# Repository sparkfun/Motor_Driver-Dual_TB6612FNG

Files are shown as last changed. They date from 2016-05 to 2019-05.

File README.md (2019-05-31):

SparkFun Motor Driver - Dual TB6612FNG (1A)
========================================

<table class="table table-hover table-striped table-bordered">
  <tr align="center">
   <td><a href="https://cdn.sparkfun.com/assets/parts/1/2/4/8/4/14451-01.jpg">SparkFun Motor Driver - Dual TB6612FNG (1A)</a></td>
   <td><a href="https://cdn.sparkfun.com/assets/parts/1/2/4/8/2/14450a-01.jpg">SPARKFUN MOTOR DRIVER - DUAL TB6612FNG (1A) with Headers</a></td>
  </tr>
  <tr align="center">
    <td>SparkFun Motor Driver - Dual TB6612FNG (1A) w/out Headers [<a href="https://www.sparkfun.com/products/14451">ROB-14451</a>]</td>
    <td>SparkFun Motor Driver - Dual TB6612FNG with Headers [<a href="https://www.sparkfun.com/products/14450">ROB-14450</a>]</td>
  </tr>
</table>

The TB6612FNG motor driver can control up to two DC motors at a constant current of 1.2A (3.2A peak). Two input signals (IN1 and IN2) can be used to control the motor in one of four function modes - CW, CCW, short-brake, and stop. The two motor outputs (A and B) can be separately controlled, the speed of each motor is controlled via a PWM input signal with a frequency up to 100kHz. The STBY pin should be pulled high to take the motor out of standby mode.

Repository Contents
-------------------

* **/Hardware** - Eagle design files (.brd, .sch)

Documentation
--------------

* **[Hookup Guide](https://learn.sparkfun.com/tutorials/tb6612fng-hookup-guide)** - Basic hookup guide for the TB6612FNG dual motor driver.
* **[SparkFun Fritzing repo](https://github.com/sparkfun/Fritzing_Parts)** - Fritzing diagrams for SparkFun products.
* **[SparkFun 3D Model repo](https://github.com/sparkfun/3D_Models)** - 3D models of SparkFun products. 

Product Versions
----------------
* [ROB-14450](https://www.sparkfun.com/products/14450)- V11 With Headers
* [ROB-14451](https://www.sparkfun.com/products/14451)- V11 Without headers
* *[ROB-13845 (RETIRED)](https://www.sparkfun.com/products/13845)- With Headers*
* *[ROB-09457 (RETIRED)](https://www.sparkfun.com/products/retired/9457)- Without headers*

Version History
---------------
* [v11](https://github.com/sparkfun/Motor_Driver-Dual_TB6612FNG/releases/tag/V_11) - Revision with Silkscreen/Components Update, v11
* [v1.1b](https://github.com/sparkfun/Motor_Driver-Dual_TB6612FNG/releases/tag/V_1.1b) - Minor update
* [v1.1](https://github.com/sparkfun/Motor_Driver-Dual_TB6612FNG/releases/tag/V_1.1) - Initial Release 

License Information
-------------------

This product is _**open source**_! 

Please review the LICENSE.md file for license information. 

If you have any questions or concerns on licensing, please contact techsupport@sparkfun.com.

Distributed as-is; no warranty is given.

- Your friends at SparkFun.

_<COLLABORATION CREDIT>_

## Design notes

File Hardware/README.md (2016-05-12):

SparkFun <PRODUCT NAME> Design Files
=====================================

The .sch and .brd files hare are Eagle CAD schematic and PCB design files from SparkFun Electronics.
A freeware version of Eagle can be found [here](http://www.cadsoftusa.com/download-eagle/freeware/).

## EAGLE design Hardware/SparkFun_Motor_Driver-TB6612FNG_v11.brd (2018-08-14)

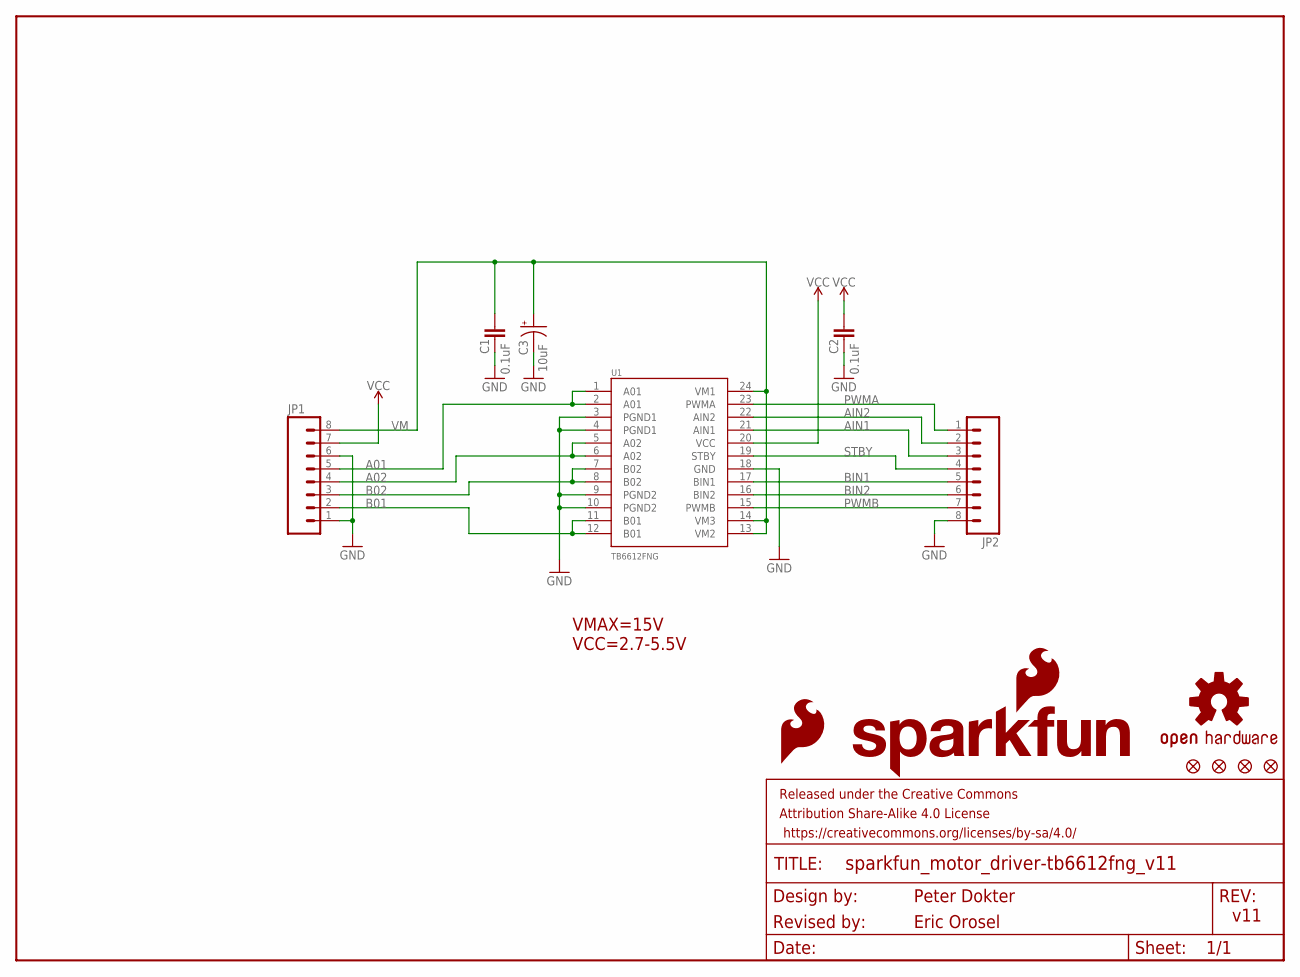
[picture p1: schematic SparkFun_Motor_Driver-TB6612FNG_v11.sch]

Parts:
C1, C2: 0.1uF; 0402
C3: 10uF; EIA3528
FD1, FD2, FD3, FD4: FIDUCIALUFIDUCIAL; FIDUCIAL-MICRO
FRAME1: FRAME-LETTER; CREATIVE_COMMONS
JP1, JP2: M0875_PERCENT_REDUCED; 1X08_OFFSET_REDUCED
LOGO1: SFE_LOGO_FLAME.1_INCH; SFE_LOGO_FLAME_.1
LOGO2: OSHW-LOGOS; OSHW-LOGO-S
LOGO4: SFE_LOGO_NAME_FLAME.1_INCH; SFE_LOGO_NAME_FLAME_.1
U1: TB6612FNG; SSOP24

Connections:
A01: JP1.5, U1.1 (A01), U1.2 (A01)
A02: JP1.4, U1.5 (A02), U1.6 (A02)
AIN1: JP2.3, U1.21 (AIN1)
AIN2: JP2.2, U1.22 (AIN2)
B01: JP1.2, U1.11 (B01), U1.12 (B01)
B02: JP1.3, U1.7 (B02), U1.8 (B02)
BIN1: JP2.5, U1.17 (BIN1)
BIN2: JP2.6, U1.16 (BIN2)
GND: C1.2, C2.2, C3.C (-), JP1.1, JP1.6, JP2.8, U1.3 (PGND1), U1.4 (PGND1), U1.9 (PGND2), U1.10 (PGND2), U1.18 (GND)
PWMA: JP2.1, U1.23 (PWMA)
PWMB: JP2.7, U1.15 (PWMB)
STBY: JP2.4, U1.19 (STBY)
VCC: C2.1, JP1.7, U1.20 (VCC)
VM: C1.1, C3.A (+), JP1.8, U1.13 (VM2), U1.14 (VM3), U1.24 (VM1)

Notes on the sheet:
v11
Peter Dokter
Revised by:
Eric Orosel
VMAX=15V VCC=2.7-5.5V

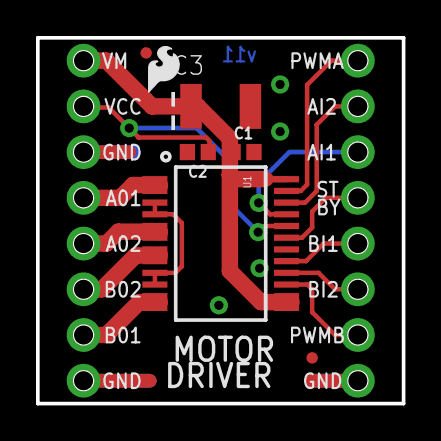
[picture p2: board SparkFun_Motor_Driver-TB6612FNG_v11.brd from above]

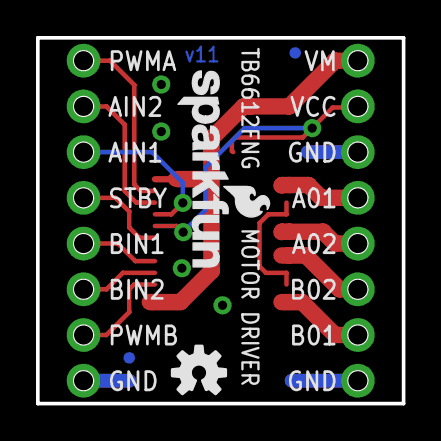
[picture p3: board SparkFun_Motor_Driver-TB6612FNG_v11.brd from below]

Board: 2 copper layers, 20.3 x 20.3 mm, 14 parts (4 on the bottom side), 14 nets.

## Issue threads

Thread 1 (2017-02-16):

Chip is mislabeled in the schematic.

Funda, 2017-02-16:
The schematic for both 09457 and 13845 label the chip incorrectly. We have the chip itself labeled "TB6621FNG" instead of "TB6612FNG".  Also, the schematic on the 13845 product page is the old v10 version.

ElhemEnohpi, 2017-09-15:
There's now an erroneous package in EasyEDA, tagged "SparkFun", which seems to be spreading this to other schematics:
https://easyeda.com/component/TB6621FNG-LmyKIGDBz
https://s3.amazonaws.com/digistump-resources/files/9adf044f_motor.pdf

ToniCorinne, 2017-09-18:
@ericorosel can you take a look at this? If we need to fix this on the updated board version, I'd like to address this.

ericorosel, 2017-09-18:
@ToniCorinne the v11 schematic symbol/package was updated the package in the "Sparkfun-" library during the revision. The v11 part/sch has the correct name.

pbbob, 2018-01-04:
@ericorosel @Funda @ElhemEnohpi @ToniCorinne @nseidle  where is the library for this part, and/or the older version? i cant find the part in the library in this repo

bboyho, 2018-08-08:
### Incorrect Value Name in TB6612FNG Board Files
To clarify on @Funda 's issue, the value was incorrectly labeled for the package. Thus the part used in the board layout and schematic files was incorrectly labeled as _TB66**21**FNG_. The value should actually be labeled as _TB66**12**FNG_. This is just a minor issue and does not affect the overall board functionality or the board symbol/package that is used in the [SparkFun Eagle Libraries](https://github.com/sparkfun/SparkFun-Eagle-Libraries).

These affect the schematic (PDF) and Eagle files (ZIP) for the following SKUs:

* [ROB-14451](https://www.sparkfun.com/products/14451) -- V11 Without Headers
* [ROB-09457](https://www.sparkfun.com/products/retired/9457) -- V10 Without Headers
* [ROB-14450](https://www.sparkfun.com/products/14450) -- V11 With Headers
* [ROB-13845](https://www.sparkfun.com/products/13845) -- V10 With Headers

### Artifacts from Cloning a Product Page
I have confirmed that the product page for [ROB-13845](https://www.sparkfun.com/products/13845) does indeed have the wrong schematic linked as @Funda stated. This is probably from the product page being cloned from the original ROB-9457breakout board but was never updated. I will let catalog know after updating the board files and exporting the schematic as a PDF.

### SparkFun Eagle Library
@pbbob , by opening up the latest Eagle board files and right clicking on the symbol/package, it is listed under SparkFun Special Function ICs

bboyho, 2018-10-23:
@Funda , Chris was able to update all the product pages. We are good now. =)

Closed 2018-10-23.

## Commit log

2016-05-12 Initial file commit
    [SparkFun_Motor_Driver-TB6612FNG.brd, SparkFun_Motor_Driver-TB6612FNG.sch]
2017-08-09 Added v11 TB6612FNG Motor Driver design files
    changes:
    -Moved and added product name silk
    -Added OSHW symbol
    -Pad shape changed to small offset
    -Silk labels added to the top of the board
    -Replace date of design w/ version number
    -Added new cc frame
    -Swapped in updated TB66xxxxx package
    -Some slight routing changes were made, but the connections are all the
    same
    [SparkFun_Motor_Driver-TB6612FNG.brd, SparkFun_Motor_Driver-TB6612FNG.sch, SparkFun_Motor_Driver-TB6612FNG_v11.brd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]
2017-08-09 Changes to design and added 1X08 conn lbr
    -moved and added/removed silk
    -moved fiducials and re routed some traces
    -added new 1X08 offset connector lbr to repo
    [SparkFun_Motor_Driver-TB6612FNG_v11.brd, SparkFun_Motor_Driver-TB6612FNG_v11.sch]
2017-08-10 Straightened some silk labels
    [SparkFun_Motor_Driver-TB6612FNG_v11.brd, SparkFun_Motor_Driver-TB6612FNG_v11.sch]
2017-08-10 Changes to SCH and BRD
    -swapped to use micro-fiducials
    -added revised by
    -completed DRC
    [SparkFun_Motor_Driver-TB6612FNG_v11.brd, SparkFun_Motor_Driver-TB6612FNG_v11.sch]
2017-08-11 changed header
    [SparkFun_Motor_Driver-TB6612FNG_v11.brd, SparkFun_Motor_Driver-TB6612FNG_v11.sch]
2017-08-11 updated part lbr
    [SparkFun_Motor_Driver-TB6612FNG_v11.brd, SparkFun_Motor_Driver-TB6612FNG_v11.sch]
2017-08-14 Changed cap parts and added measures
    -Replaced 0603 caps with caps from the sparkfun-capacitors lbr
    -Replaced 10uf cap with cap from the sparkfun-capacitors lbr
    -added measures to the design
    [SparkFun_Motor_Driver-TB6612FNG_v11.brd, SparkFun_Motor_Driver-TB6612FNG_v11.sch]
2017-08-14 schematic tweaks from double-check
    -gave each VCC pin it's own net and VCC symbol
    [SparkFun_Motor_Driver-TB6612FNG_v11.brd, SparkFun_Motor_Driver-TB6612FNG_v11.sch]
2018-08-14 Update IC Value
    Regarding this issue [ https://github.com/sparkfun/Motor_Driver-Dual_TB6612FNG/issues/1 ].
    The part used in the board layout and schematic files was incorrectly labeled as TB6621FNG. The value should actually be labeled as TB6612FNG.
    [SparkFun_Motor_Driver-TB6612FNG.brd, SparkFun_Motor_Driver-TB6612FNG.sch]
2018-08-14 Merge Conflict
    Moving to desktop temporarily.
    [SparkFun_Motor_Driver-TB6612FNG_v11.brd, SparkFun_Motor_Driver-TB6612FNG_v11.sch]
2018-08-14 Merge Conflict
    Re-adding to v11 branch
    [SparkFun_Motor_Driver-TB6612FNG_v11.brd, SparkFun_Motor_Driver-TB6612FNG_v11.sch]
2018-08-14 Merge Conflict w/ latest board files
    Files are tagged here if we need to go back => https://github.com/sparkfun/Motor_Driver-Dual_TB6612FNG/releases/tag/V_1.1b
    [SparkFun_Motor_Driver-TB6612FNG.brd]

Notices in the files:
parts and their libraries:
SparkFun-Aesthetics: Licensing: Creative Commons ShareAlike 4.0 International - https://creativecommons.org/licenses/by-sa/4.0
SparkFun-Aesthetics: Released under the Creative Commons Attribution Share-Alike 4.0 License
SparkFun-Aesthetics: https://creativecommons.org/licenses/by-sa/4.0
